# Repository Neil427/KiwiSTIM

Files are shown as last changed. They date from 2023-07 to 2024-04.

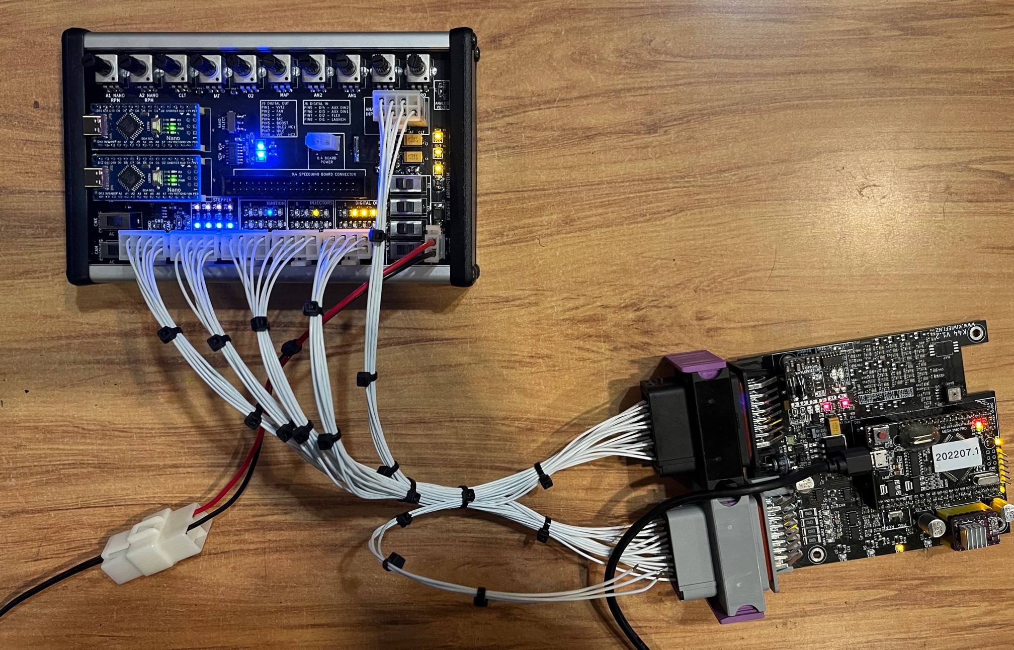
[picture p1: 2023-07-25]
KiwiSTIM.jpg

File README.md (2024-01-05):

# KiwiSTIM
KiwiSTIM is a engine simulator used for testing engine management computers, it is variation of Ardustim and uses the Ardustim firmware. 
It has 2 Nanos for 2 switchable trigger setups, 2x crank/cam leds, 8x analog pots, 8x injector leds, 8x ignition leds, 8x digital output leds, stepper iac leds, 4x digital input switches.



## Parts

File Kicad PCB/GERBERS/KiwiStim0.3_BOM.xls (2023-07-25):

Ref | Qnty | Value
A1, A2 | 2 | ArduinoNANO
C1, C3, C4, C10, C13 | 5 | 100N 0805
C2, C6 | 2 | 22uF 25V
C5, C7, C8, C9, C11, C12, C14 | 7 | 1uF 0805
D1 | 1 | RED LED 0805
D2 | 1 | GREEN LED 0805
D3 | 1 | GREEN LED 0805
D4 | 1 | BLUE LED 0805
D5 | 1 | BLUE LED 0805
D6 | 1 | B360
D7, D8, D9, D10, D11, D12, D13, D14, D15, D16, D17, D18, D19, D20, D21 | 15 | YELLOW LED 0805
D22, D23, D24, D25, D26, D27, D28, D29, D30, D31, D32, D33, D34, D35, D36, D37, D38 | 17 | YELLOW LED 0805
F1 | 1 | 0.5A POWER
F2 | 1 | 0.2A ECU VREF
F3 | 1 | 1A POWER
R1, R2, R6, R7, R8,R9,R10, R11 | 8 | 470R 0805
R3, R4, R5, R12, R13, R14, R15, R16, R17, R18, R19, R20, R21, R22, R23, R24, R25 | 17 | 1K 0805
R26, R27, R28, R29, R30, R31, R32, R33, R34, R35, R36, R37, R38, R39, R40, R41, R42, R43 | 18 | 1K 0805
R44, R45, R46, R47 | 4 | 220R 0805
R48, R49 | 2 | 10K 0805
RV1, RV2, RV3, RV4, RV5, RV6, RV7, RV8, RV9, RV10 | 10 | 10K RV09 VERT POT
U1 | 1 | 74HC14
U2 | 1 | LM2937-5
U3 | 1 | VNLD5090

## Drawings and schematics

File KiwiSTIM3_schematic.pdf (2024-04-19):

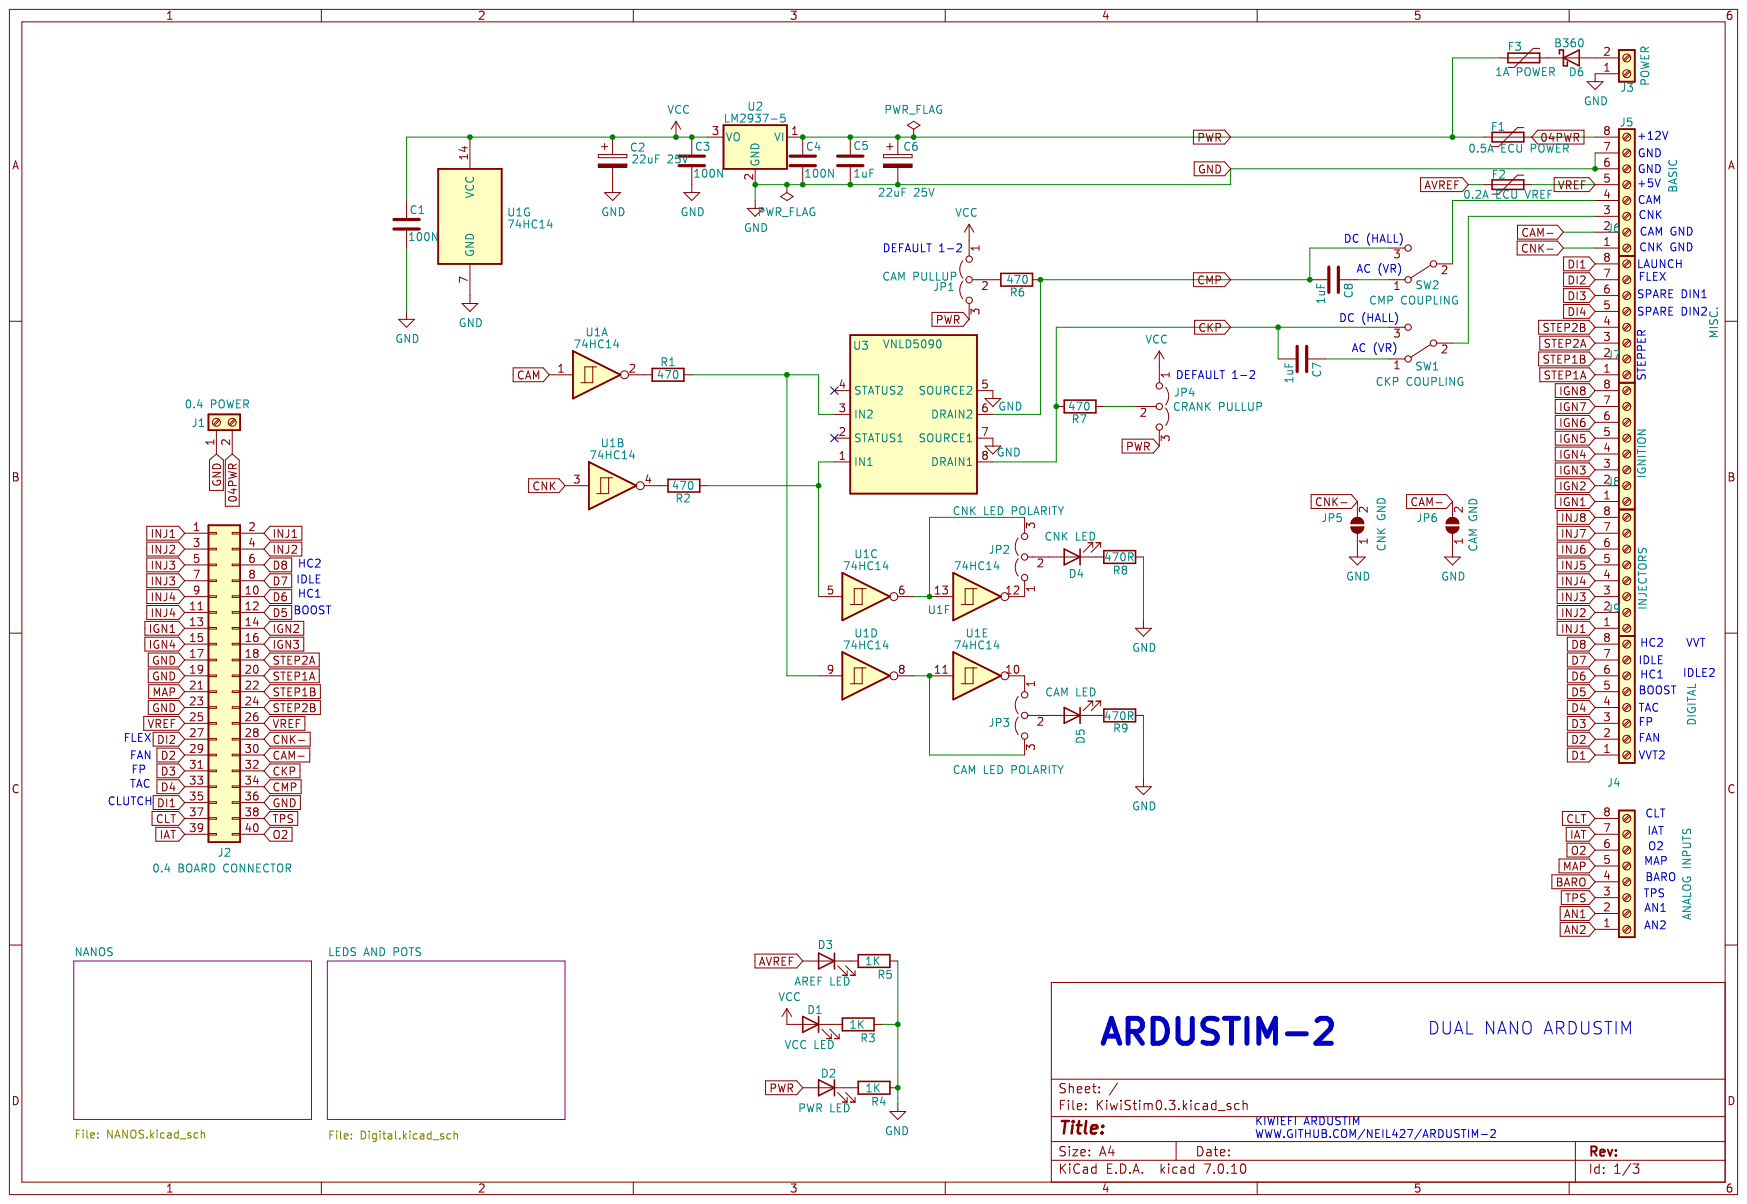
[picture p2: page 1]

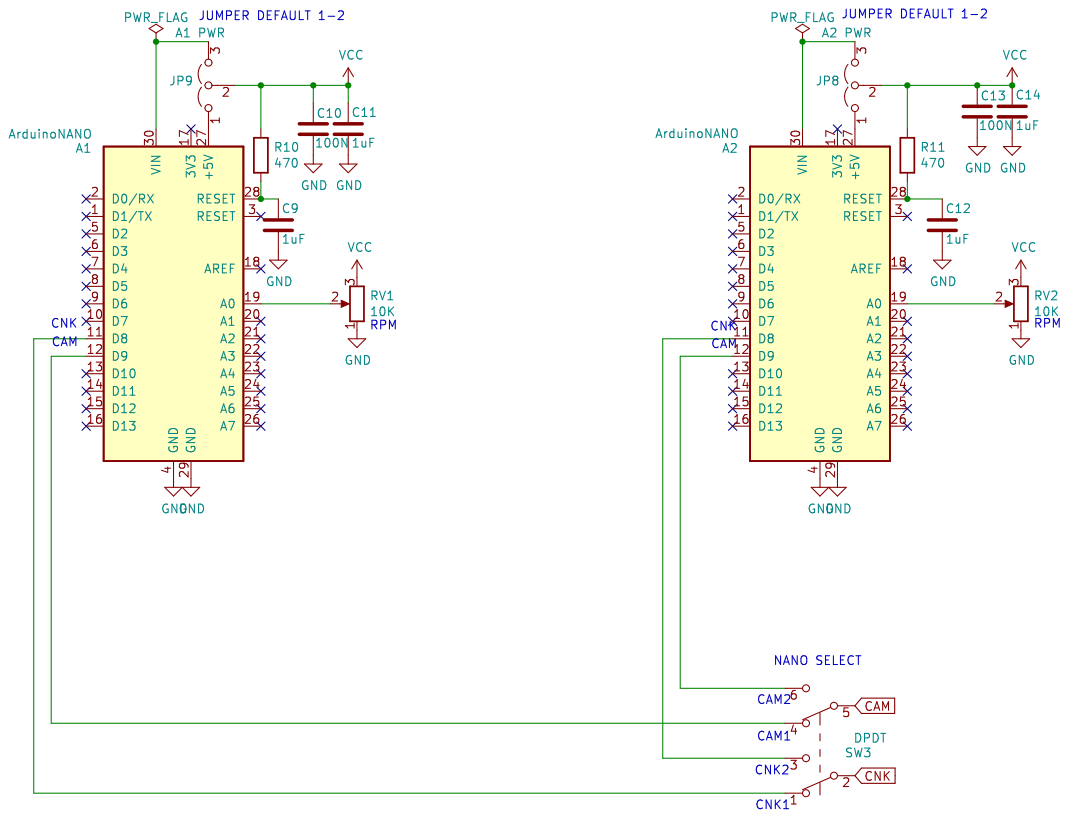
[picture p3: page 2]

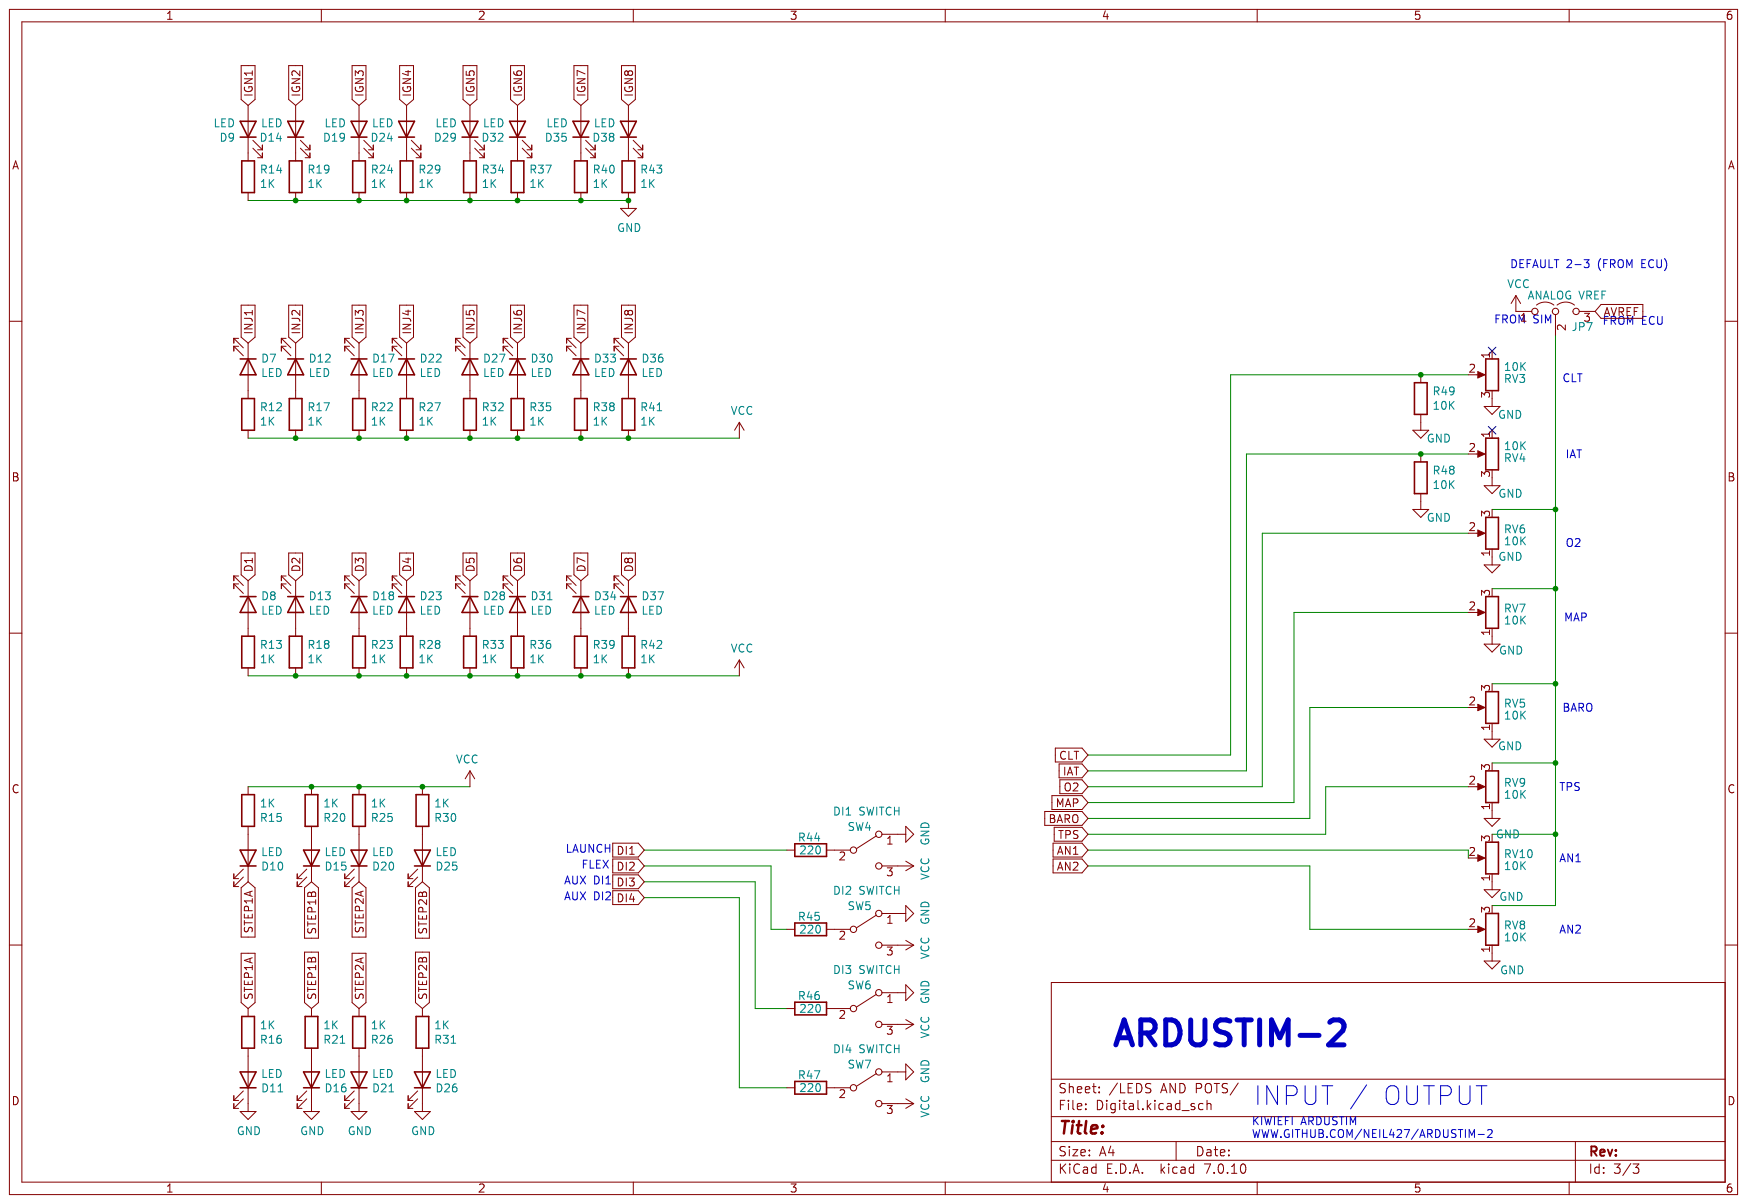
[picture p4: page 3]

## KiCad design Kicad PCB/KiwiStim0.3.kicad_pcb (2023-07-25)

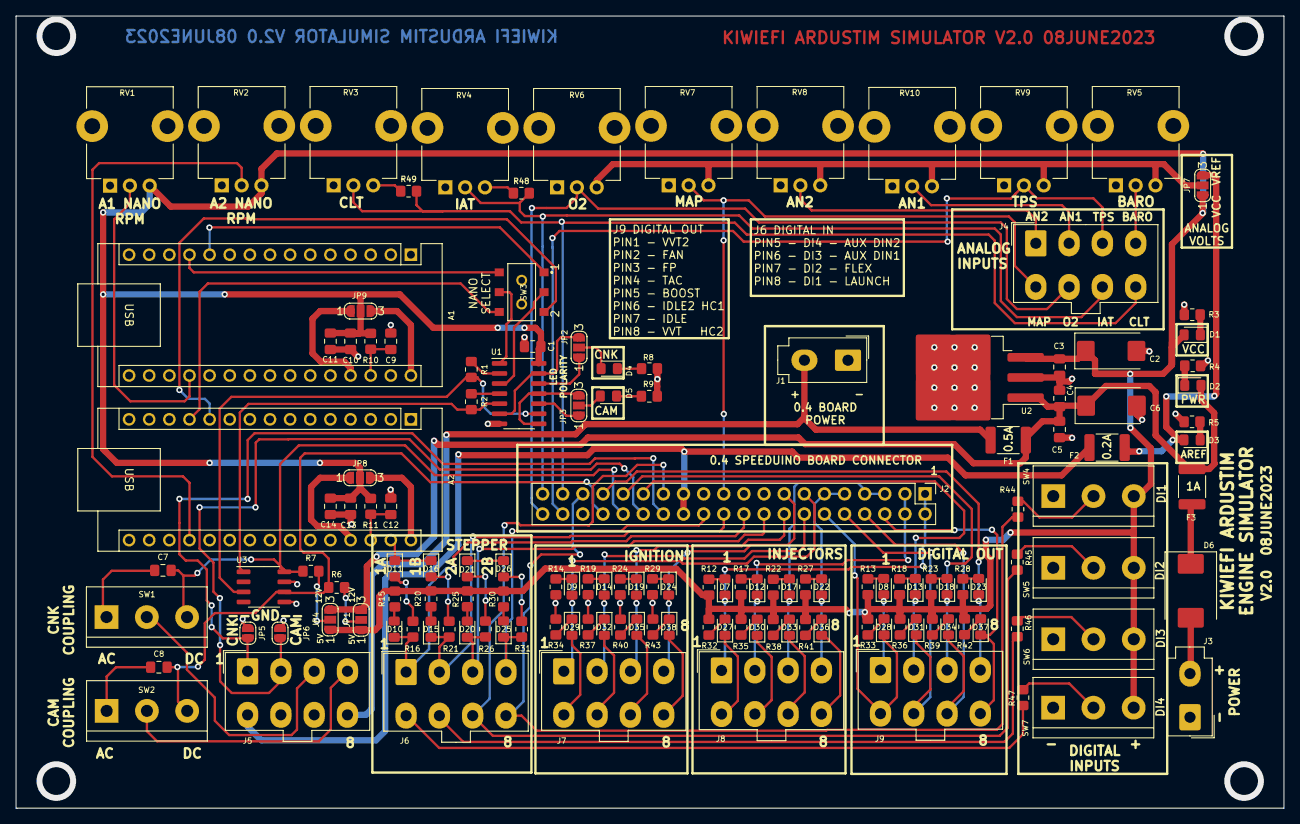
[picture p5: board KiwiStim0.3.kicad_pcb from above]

Board: 2 copper layers, 160.0 x 99.9 mm, 144 parts (0 on the bottom side), 124 nets.

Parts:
A1, A2: ArduinoNANO; Arduino_Nano
C1, C3, C4, C10, C13: 100N; C_0805_2012Metric_Pad1.18x1.45mm_HandSolder
C2, C6: 22uF 25V; CP_EIA-7343-31_Kemet-D_Pad2.25x2.55mm_HandSolder
C5, C7, C8, C9, C11, C12, C14: 1uF; C_0805_2012Metric_Pad1.18x1.45mm_HandSolder
D1: VCC LED; LED_0805_2012Metric_Pad1.15x1.40mm_HandSolder
D2: PWR LED; LED_0805_2012Metric_Pad1.15x1.40mm_HandSolder
D3: AREF LED; LED_0805_2012Metric_Pad1.15x1.40mm_HandSolder
D4: CNK LED; LED_0805_2012Metric_Pad1.15x1.40mm_HandSolder
D5: CAM LED; LED_0805_2012Metric_Pad1.15x1.40mm_HandSolder
D6: B360; D_SMC
D7, D8, D9, D10, D11, D12, D13, D14, D15, D16, D17, D18, D19, D20, D21, D22, D23, D24, D25, D26, D27, D28, D29, D30, D31, D32, D33, D34, D35, D36, D37, D38: LED; LED_0805_2012Metric_Pad1.15x1.40mm_HandSolder
F1: 0.5A ECU POWER; Fuse_1812_4532Metric_Pad1.30x3.40mm_HandSolder
F2: 0.2A ECU VREF; Fuse_1812_4532Metric_Pad1.30x3.40mm_HandSolder
F3: 1A POWER; Fuse_1812_4532Metric_Pad1.30x3.40mm_HandSolder
J1: 0.4 POWER; Molex_Mini-Fit_Jr_5566-02A_2x01_P4.20mm_Vertical
J2: 0.4 BOARD CONNECTOR; PinHeader_2x20_P2.54mm_Vertical
J3: POWER; Molex_Mini-Fit_Jr_5566-02A_2x01_P4.20mm_Vertical
J4: ANALOG INPUTS; Molex_Mini-Fit_Jr_5566-08A_2x04_P4.20mm_Vertical
J5: BASIC; Molex_Mini-Fit_Jr_5566-08A_2x04_P4.20mm_Vertical
J6: MISC.; Molex_Mini-Fit_Jr_5566-08A_2x04_P4.20mm_Vertical
J7: IGNITION; Molex_Mini-Fit_Jr_5566-08A_2x04_P4.20mm_Vertical
J8: INJECTORS; Molex_Mini-Fit_Jr_5566-08A_2x04_P4.20mm_Vertical
J9: DIGITAL; Molex_Mini-Fit_Jr_5566-08A_2x04_P4.20mm_Vertical
JP1: CAM PULLUP; SolderJumper-3_P1.3mm_Open_RoundedPad1.0x1.5mm_NumberLabels
JP2: CNK LED POLARITY; SolderJumper-3_P1.3mm_Open_RoundedPad1.0x1.5mm_NumberLabels
JP3: CAM LED POLARITY; SolderJumper-3_P1.3mm_Open_RoundedPad1.0x1.5mm_NumberLabels
JP4: CRANK PULLUP; SolderJumper-3_P1.3mm_Open_RoundedPad1.0x1.5mm_NumberLabels
JP5: CNK GND; SolderJumper-2_P1.3mm_Open_RoundedPad1.0x1.5mm
JP6: CAM GND; SolderJumper-2_P1.3mm_Open_RoundedPad1.0x1.5mm
JP7: ANALOG VREF; SolderJumper-3_P1.3mm_Open_RoundedPad1.0x1.5mm_NumberLabels
JP8: A2 PWR; SolderJumper-3_P1.3mm_Open_RoundedPad1.0x1.5mm_NumberLabels
JP9: A1 PWR; SolderJumper-3_P1.3mm_Open_RoundedPad1.0x1.5mm_NumberLabels
R1, R2, R6, R7, R10, R11: 470; R_0805_2012Metric_Pad1.20x1.40mm_HandSolder
R3, R4, R5, R12, R13, R14, R15, R16, R17, R18, R19, R20, R21, R22, R23, R24, R25, R26, R27, R28, R29, R30, R31, R32, R33, R34, R35, R36, R37, R38, R39, R40, R41, R42, R43: 1K; R_0805_2012Metric_Pad1.20x1.40mm_HandSolder
R8, R9: 470R; R_0805_2012Metric_Pad1.20x1.40mm_HandSolder
R44, R45, R46, R47: 220; R_0805_2012Metric_Pad1.20x1.40mm_HandSolder
R48, R49: 10K; R_0805_2012Metric_Pad1.20x1.40mm_HandSolder
RV1, RV2, RV3, RV4, RV5, RV6, RV7, RV8, RV9, RV10: 10K; Potentiometer_TT_P0915N
SW1: CKP COUPLING; TerminalBlock_bornier-3_P5.08mm
SW2: CMP COUPLING; TerminalBlock_bornier-3_P5.08mm
SW3: DPDT; AYZ0202AGRLC
SW4: DI1 SWITCH; TerminalBlock_bornier-3_P5.08mm
SW5: DI2 SWITCH; TerminalBlock_bornier-3_P5.08mm
SW6: DI3 SWITCH; TerminalBlock_bornier-3_P5.08mm
SW7: DI4 SWITCH; TerminalBlock_bornier-3_P5.08mm
U1: 74HC14; SOIC-14_3.9x8.7mm_P1.27mm
U2: LM2937-5; TO-263-3_TabPin2
U3: VNLD5090; SO-8_3.9x4.9mm_P1.27mm

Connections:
04PWR: F1.2, J1.2, J5.8
AN1: J4.2, RV10.2
AN2: J4.1, RV8.2
AVREF: D3.2 (A), F2.1, JP7.3 (B)
BARO: J4.4, RV5.2
CAM: SW3.5 (B), U1.1
CAM-: J2.30, J5.2, JP6.2 (B)
CKP: C7.2, J2.32, R7.1, SW1.3 (C), U3.8 (DRAIN1)
CLT: J2.37, J4.8, R49.1, RV3.2
CMP: C8.2, J2.34, R6.1, SW2.3 (C), U3.6 (DRAIN2)
CNK: SW3.2 (B), U1.3
CNK-: J2.28, J5.1, JP5.2 (B)
D1: D8.1 (K), J9.1
D2: D13.1 (K), J2.29, J9.2
D3: D18.1 (K), J2.31, J9.3
D4: D23.1 (K), J2.33, J9.4
D5: D28.1 (K), J2.12, J9.5
D6: D31.1 (K), J2.10, J9.6
D7: D34.1 (K), J2.8, J9.7
D8: D37.1 (K), J2.6, J9.8
DI1: J2.35, J6.8, R44.1
DI2: J2.27, J6.7, R45.1
DI3: J6.6, R46.1
DI4: J6.5, R47.1
GND: A1.4 (GND), A1.29 (GND), A2.4 (GND), A2.29 (GND), C1.2, C2.2, C3.2, C4.2, C5.2, C6.2, C9.2, C10.2, C11.2, C12.2, C13.2, C14.2, D11.1 (K), D16.1 (K), D21.1 (K), D26.1 (K), J1.1, J2.17, J2.19, J2.23, J2.36, J3.1, J5.6, J5.7, JP5.1 (A), JP6.1 (A), R3.2, R4.2, R5.2, R8.2, R9.2, R14.2, R19.2, R24.2, R29.2, R34.2, R37.2, R40.2, R43.2, R48.2, R49.2, RV1.1, RV2.1, RV3.3, RV4.3, RV5.1, RV6.1, RV7.1, RV8.1, RV9.1, RV10.1, SW4.1 (A), SW5.1 (A), SW6.1 (A), SW7.1 (A), U1.7 (GND), U2.2 (GND), U3.5 (SOURCE2), U3.7 (SOURCE1)
IAT: J2.39, J4.7, R48.1, RV4.2
IGN1: D9.2 (A), J2.13, J7.1
IGN2: D14.2 (A), J2.14, J7.2
IGN3: D19.2 (A), J2.16, J7.3
IGN4: D24.2 (A), J2.15, J7.4
IGN5: D29.2 (A), J7.5
IGN6: D32.2 (A), J7.6
IGN7: D35.2 (A), J7.7
IGN8: D38.2 (A), J7.8
INJ1: D7.1 (K), J2.1, J2.2, J8.1
INJ2: D12.1 (K), J2.3, J2.4, J8.2
INJ3: D17.1 (K), J2.5, J2.7, J8.3
INJ4: D22.1 (K), J2.9, J2.11, J8.4
INJ5: D27.1 (K), J8.5
INJ6: D30.1 (K), J8.6
INJ7: D33.1 (K), J8.7
INJ8: D36.1 (K), J8.8
MAP: J2.21, J4.5, RV7.2
unnamed: A1.27 (+5V), JP9.1 (A)
unnamed: A1.19 (A0), RV1.2
unnamed: A1.11 (D8), SW3.1 (A)
unnamed: A1.12 (D9), SW3.4 (A)
unnamed: A1.28 (RESET), C9.1, R10.2
unnamed: A1.30 (VIN), JP9.3 (B)
unnamed: A2.27 (+5V), JP8.1 (A)
unnamed: A2.19 (A0), RV2.2
unnamed: A2.11 (D8), SW3.3 (C)
unnamed: A2.12 (D9), SW3.6 (C)
unnamed: A2.28 (RESET), C12.1, R11.2
unnamed: A2.30 (VIN), JP8.3 (B)
unnamed: D1.1 (K), R3.1
unnamed: D2.1 (K), R4.1
unnamed: D3.1 (K), R5.1
unnamed: D4.2 (A), JP2.2 (C)
unnamed: D4.1 (K), R8.1
unnamed: D5.2 (A), JP3.2 (C)
unnamed: D5.1 (K), R9.1
unnamed: D6.2 (A), J3.2
unnamed: D6.1 (K), F3.2
unnamed: D7.2 (A), R12.1
unnamed: D8.2 (A), R13.1
unnamed: D9.1 (K), R14.1
unnamed: D10.2 (A), R15.1
unnamed: D11.2 (A), R16.1
unnamed: D12.2 (A), R17.1
unnamed: D13.2 (A), R18.1
unnamed: D14.1 (K), R19.1
unnamed: D15.2 (A), R20.1
unnamed: D16.2 (A), R21.1
unnamed: D17.2 (A), R22.1
unnamed: D18.2 (A), R23.1
unnamed: D19.1 (K), R24.1
unnamed: D20.2 (A), R25.1
unnamed: D21.2 (A), R26.1
unnamed: D22.2 (A), R27.1
unnamed: D23.2 (A), R28.1
unnamed: D24.1 (K), R29.1
unnamed: D25.2 (A), R30.1
unnamed: D26.2 (A), R31.1
unnamed: D27.2 (A), R32.1
unnamed: D28.2 (A), R33.1
unnamed: D29.1 (K), R34.1
unnamed: D30.2 (A), R35.1
unnamed: D31.2 (A), R36.1
unnamed: D32.1 (K), R37.1
unnamed: D33.2 (A), R38.1
unnamed: D34.2 (A), R39.1
unnamed: D35.1 (K), R40.1
unnamed: D36.2 (A), R41.1
unnamed: D37.2 (A), R42.1
unnamed: D38.1 (K), R43.1
unnamed: J5.3, SW1.2 (B)
unnamed: J5.4, SW2.2 (B)
unnamed: JP1.2 (C), R6.2
unnamed: JP2.1 (A), U1.12
unnamed: JP2.3 (B), U1.6, U1.13
unnamed: JP3.1 (A), U1.10
unnamed: JP3.3 (B), U1.8, U1.11
unnamed: JP4.2 (C), R7.2
unnamed: JP7.2 (C), RV5.3, RV6.3, RV7.3, RV8.3, RV9.3, RV10.3
unnamed: R1.1, U1.2
unnamed: R2.1, U1.4
unnamed: C7.1, SW1.1 (A)
unnamed: C8.1, SW2.1 (A)
unnamed: R44.2, SW4.2 (B)
unnamed: R45.2, SW5.2 (B)
unnamed: R46.2, SW6.2 (B)
unnamed: R47.2, SW7.2 (B)
unnamed: R2.2, U1.5, U3.1 (IN1)
unnamed: R1.2, U1.9, U3.3 (IN2)
O2: J2.40, J4.6, RV6.2
PWR: C4.1, C5.1, C6.1, D2.2 (A), F1.1, F3.1, JP1.3 (B), JP4.3 (B), U2.1 (VI)
STEP1A: D10.1 (K), J2.20, J6.1, R16.2
STEP1B: D15.1 (K), J2.22, J6.2, R21.2
STEP2A: D20.1 (K), J2.18, J6.3, R26.2
STEP2B: D25.1 (K), J2.24, J6.4, R31.2
TPS: J2.38, J4.3, RV9.2
VCC: C1.1, C2.1, C3.1, C10.1, C11.1, C13.1, C14.1, D1.2 (A), JP1.1 (A), JP4.1 (A), JP7.1 (A), JP8.2 (C), JP9.2 (C), R10.1, R11.1, R12.2, R13.2, R15.2, R17.2, R18.2, R20.2, R22.2, R23.2, R25.2, R27.2, R28.2, R30.2, R32.2, R33.2, R35.2, R36.2, R38.2, R39.2, R41.2, R42.2, RV1.3, RV2.3, SW4.3 (C), SW5.3 (C), SW6.3 (C), SW7.3 (C), U1.14 (VCC), U2.3 (VO)
VREF: F2.2, J2.25, J2.26, J5.5
